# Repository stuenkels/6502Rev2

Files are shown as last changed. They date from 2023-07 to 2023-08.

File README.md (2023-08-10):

# 6502v2 Computer Build

Please note while this design is based on Ben Eaters 6502 (eater.net/6502) computer, it is not 100% compatible. This is mostly due to the memory map being changed to make space for 3 interface chips, 2 c22s and a c51. 

Memory Map:
  0x0000 -> 0x3FFF : RAM
  0x4010 : Start of memory for the "GPIO" VIA
  0x4020 : Start of memory for the "LCD" VIA
  0x4040 : Start of memory for the Serial interface
  0x8000 -> 0xFFFF : ROM

It is very simple to refactor any code written for the BE6502 to work with this design, all you have to do is change the definitions for the different ports, ex PORTB = $6020 would be PORTB = $4020.  

# Pictures
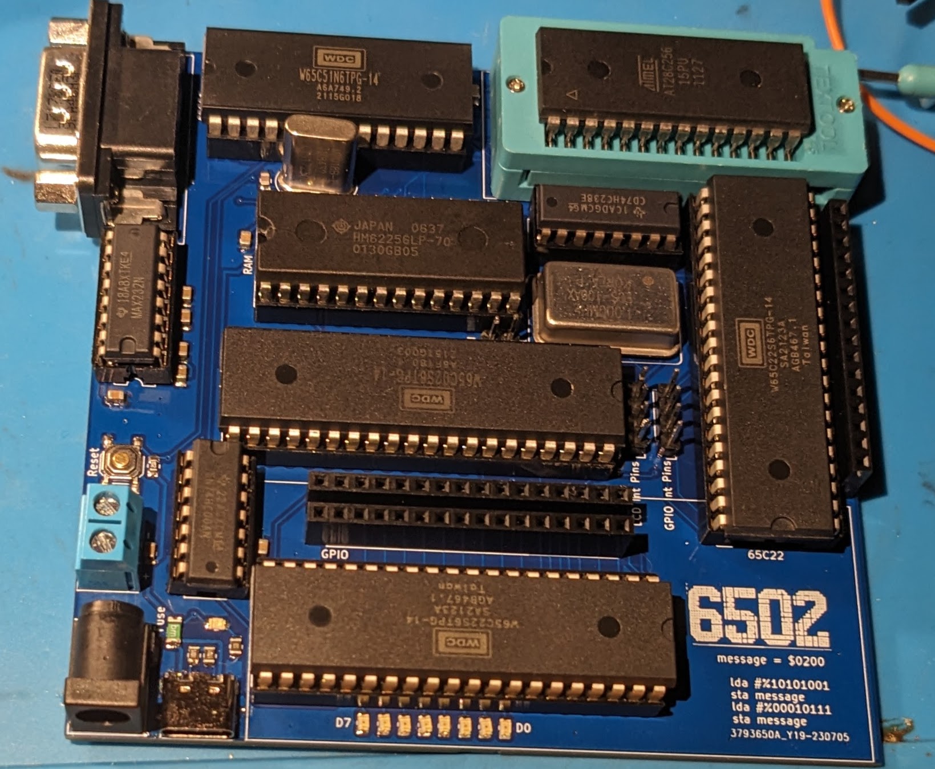
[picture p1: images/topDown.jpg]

<br>
The LCD header was mirrored on this first run of boards, the GERBER files and KiCad project have been updated in the repo.

If you want to build this PCB yourself, you can download the gerber.zip file and order it from JLCPCB or PCBWAY
MAKE SURE TO USE A FEMALE DB9 CONNECTOR FOR THE SERIAL PORT!!! The connecture in the picture is a male connector, and it does not work because the pins are in the wrong spots!

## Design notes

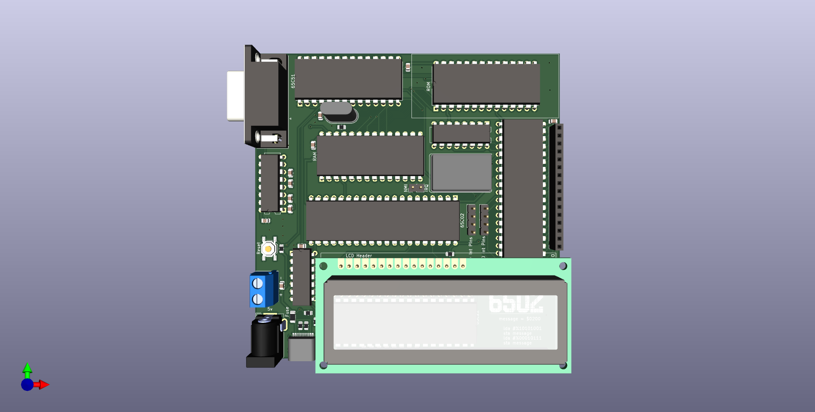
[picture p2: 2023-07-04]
images/pcb-3dRender.png

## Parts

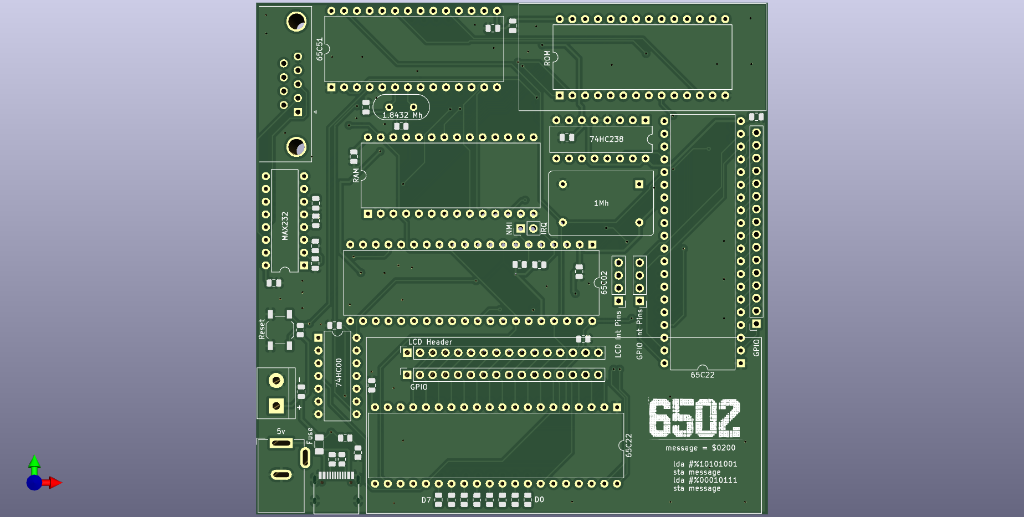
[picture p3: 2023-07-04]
images/pcb-3dWithoutComponents.png

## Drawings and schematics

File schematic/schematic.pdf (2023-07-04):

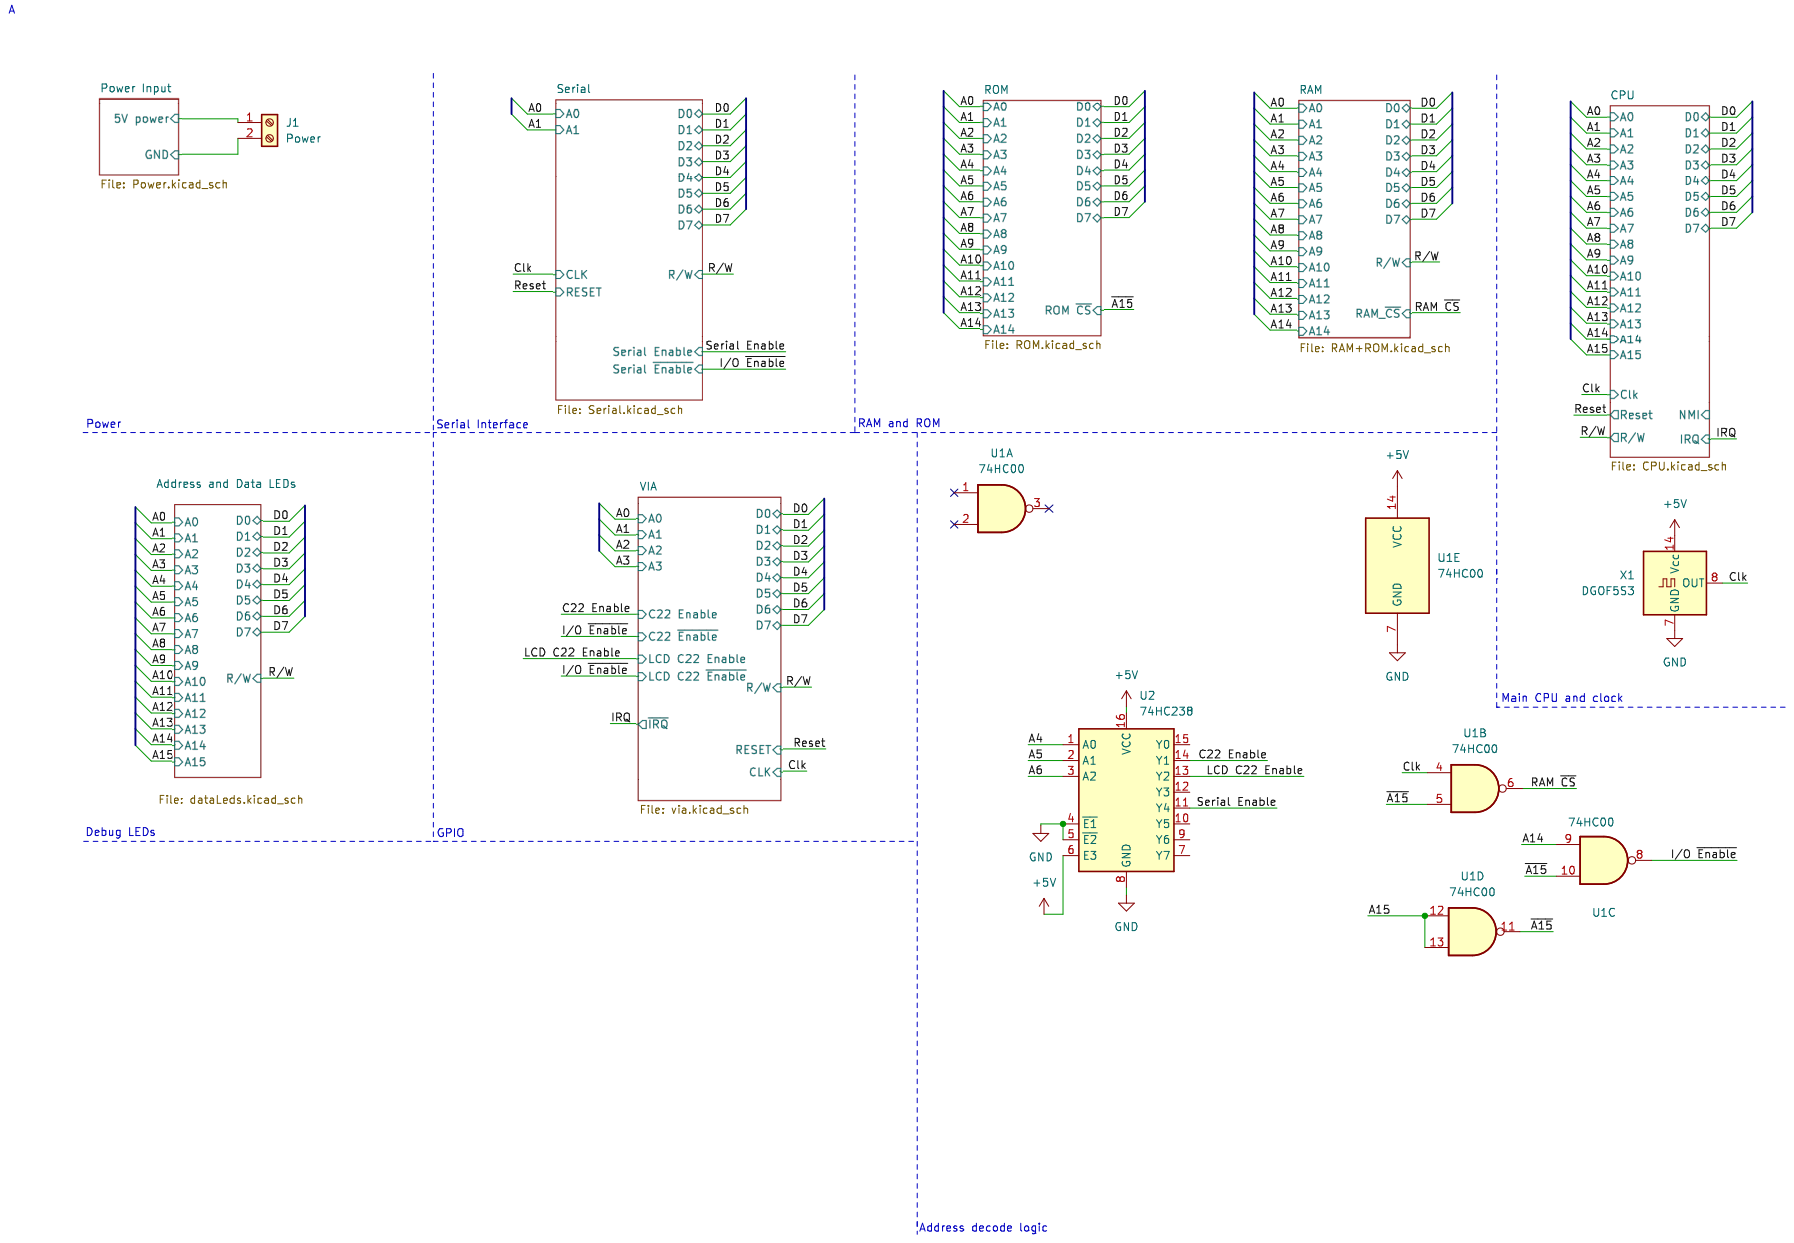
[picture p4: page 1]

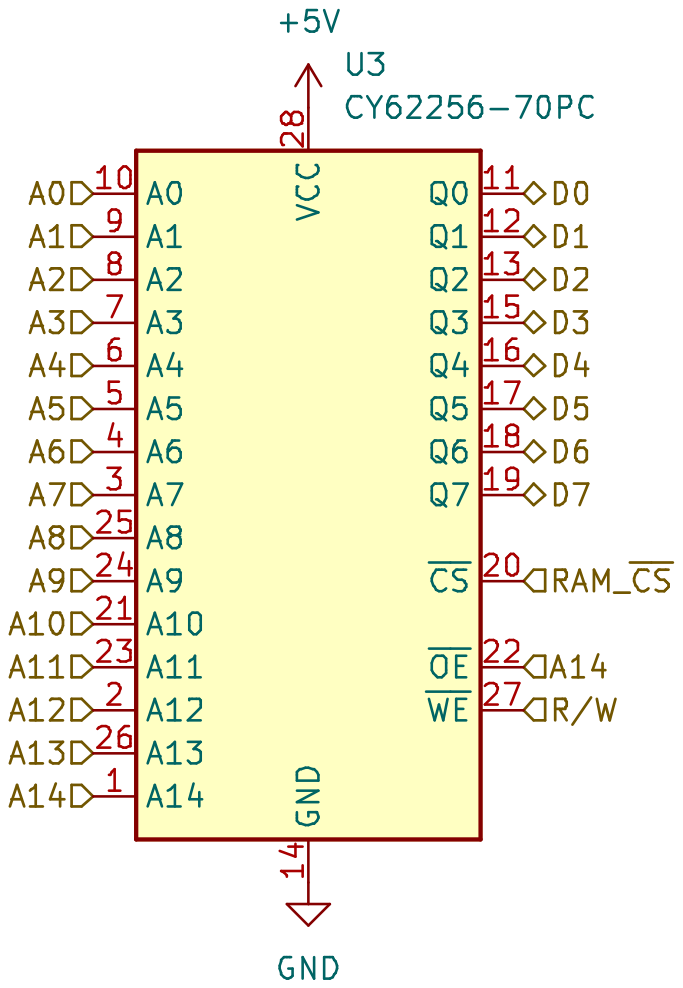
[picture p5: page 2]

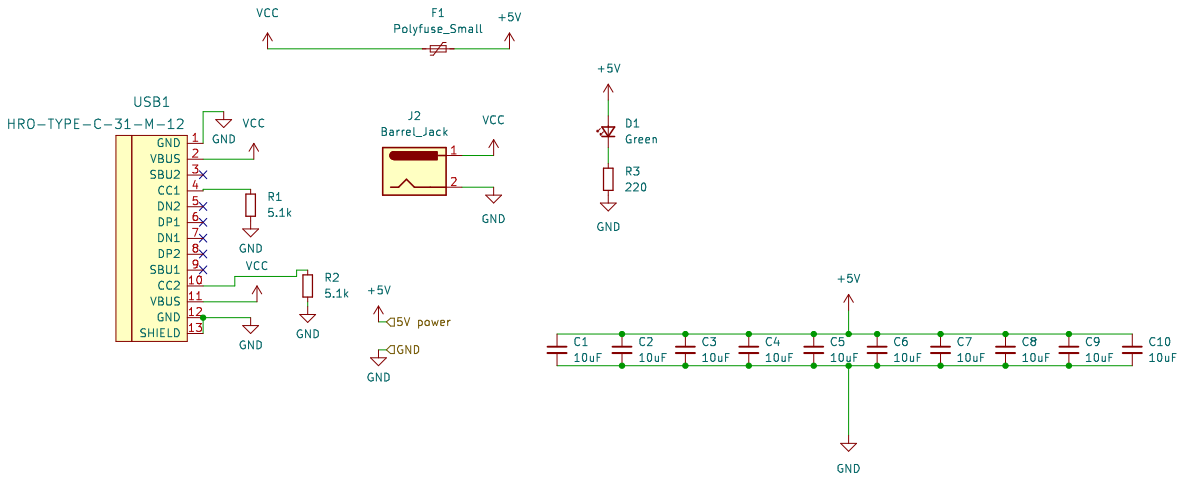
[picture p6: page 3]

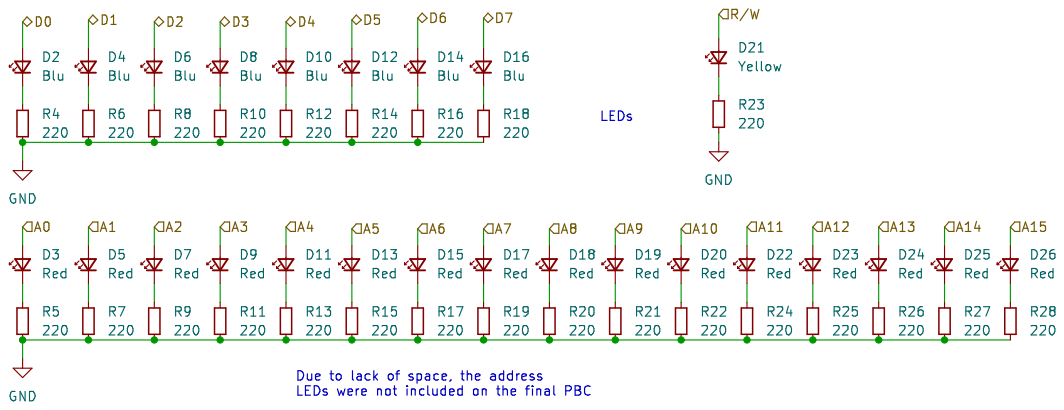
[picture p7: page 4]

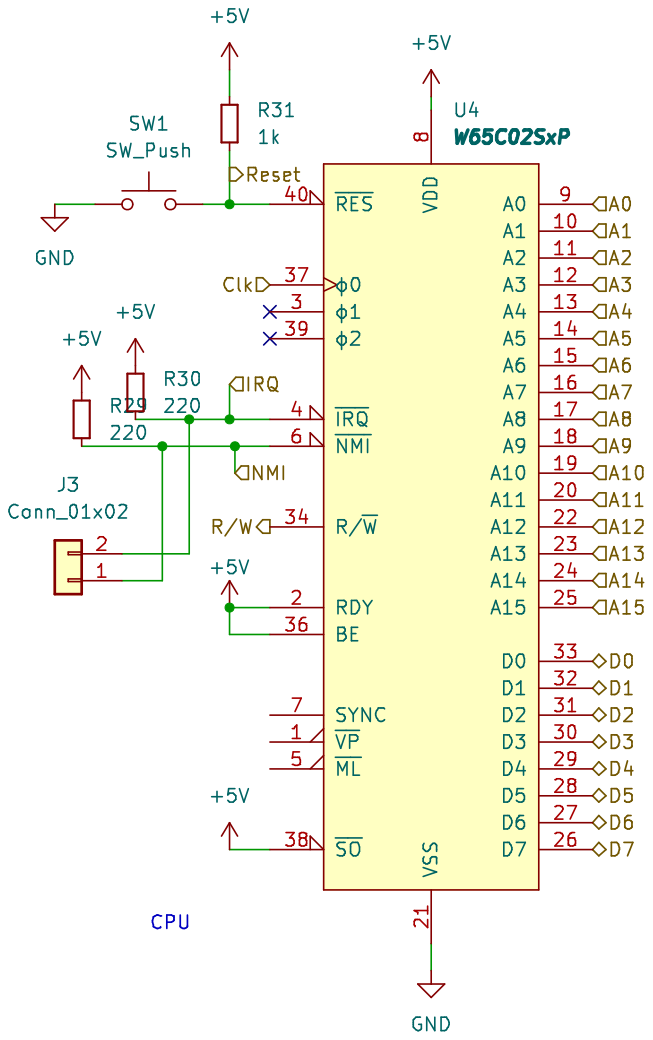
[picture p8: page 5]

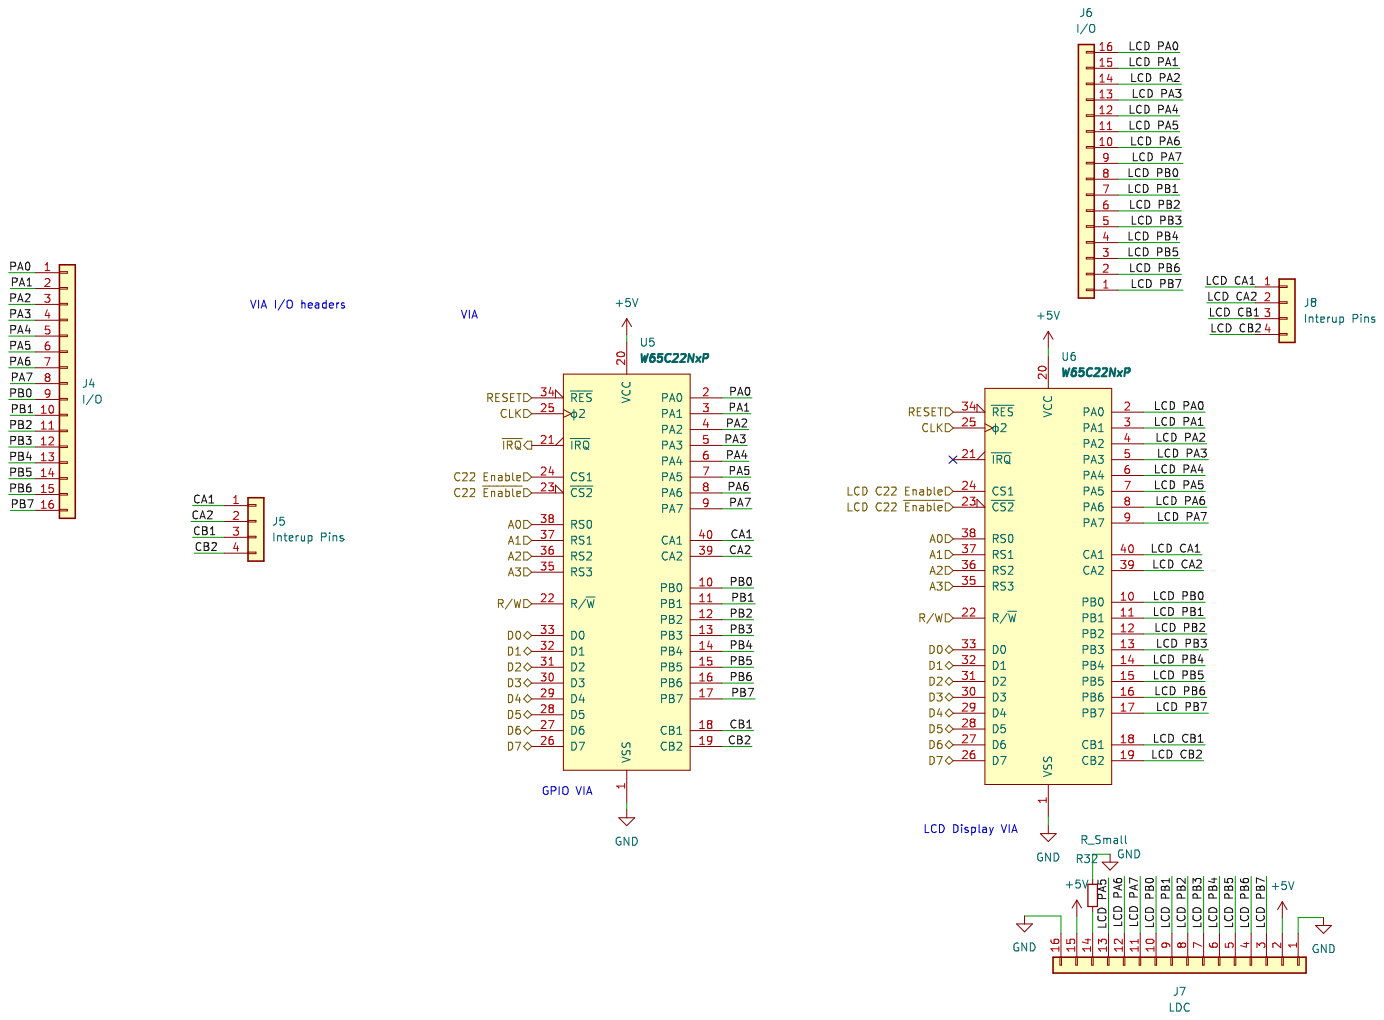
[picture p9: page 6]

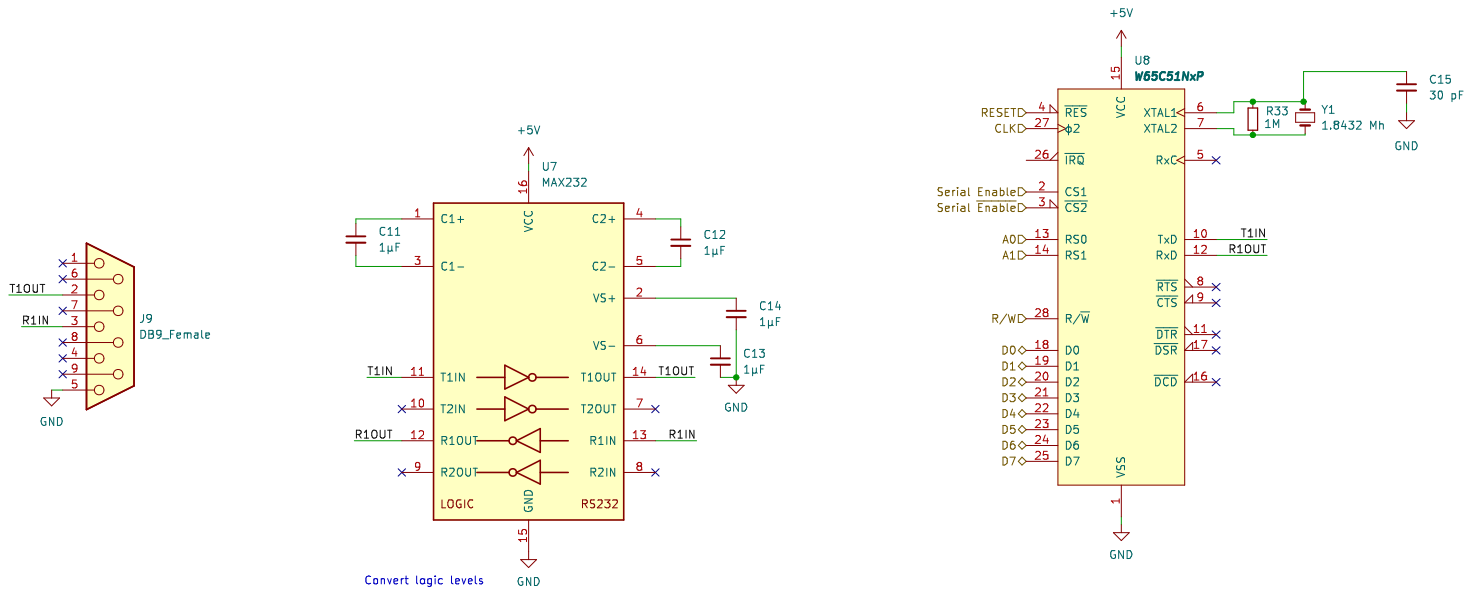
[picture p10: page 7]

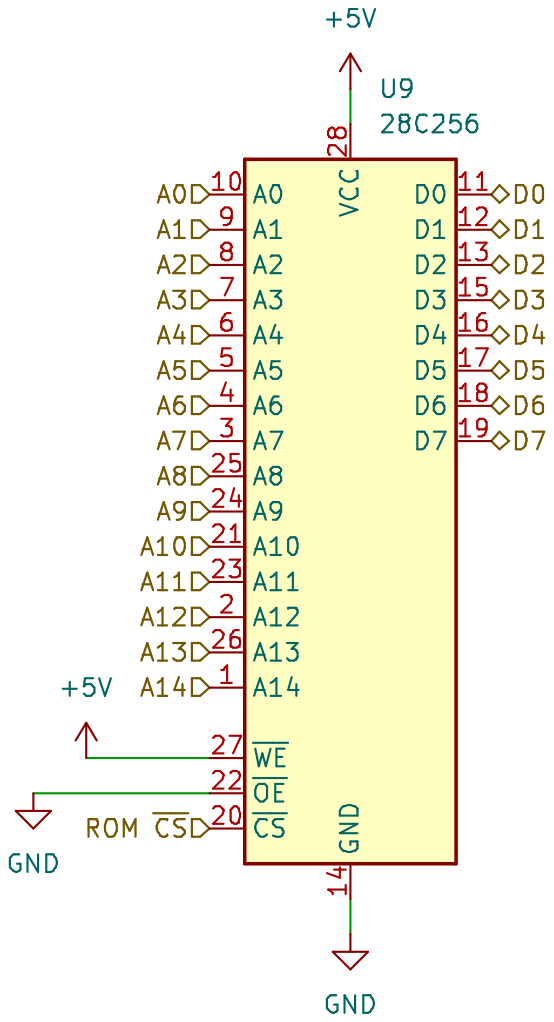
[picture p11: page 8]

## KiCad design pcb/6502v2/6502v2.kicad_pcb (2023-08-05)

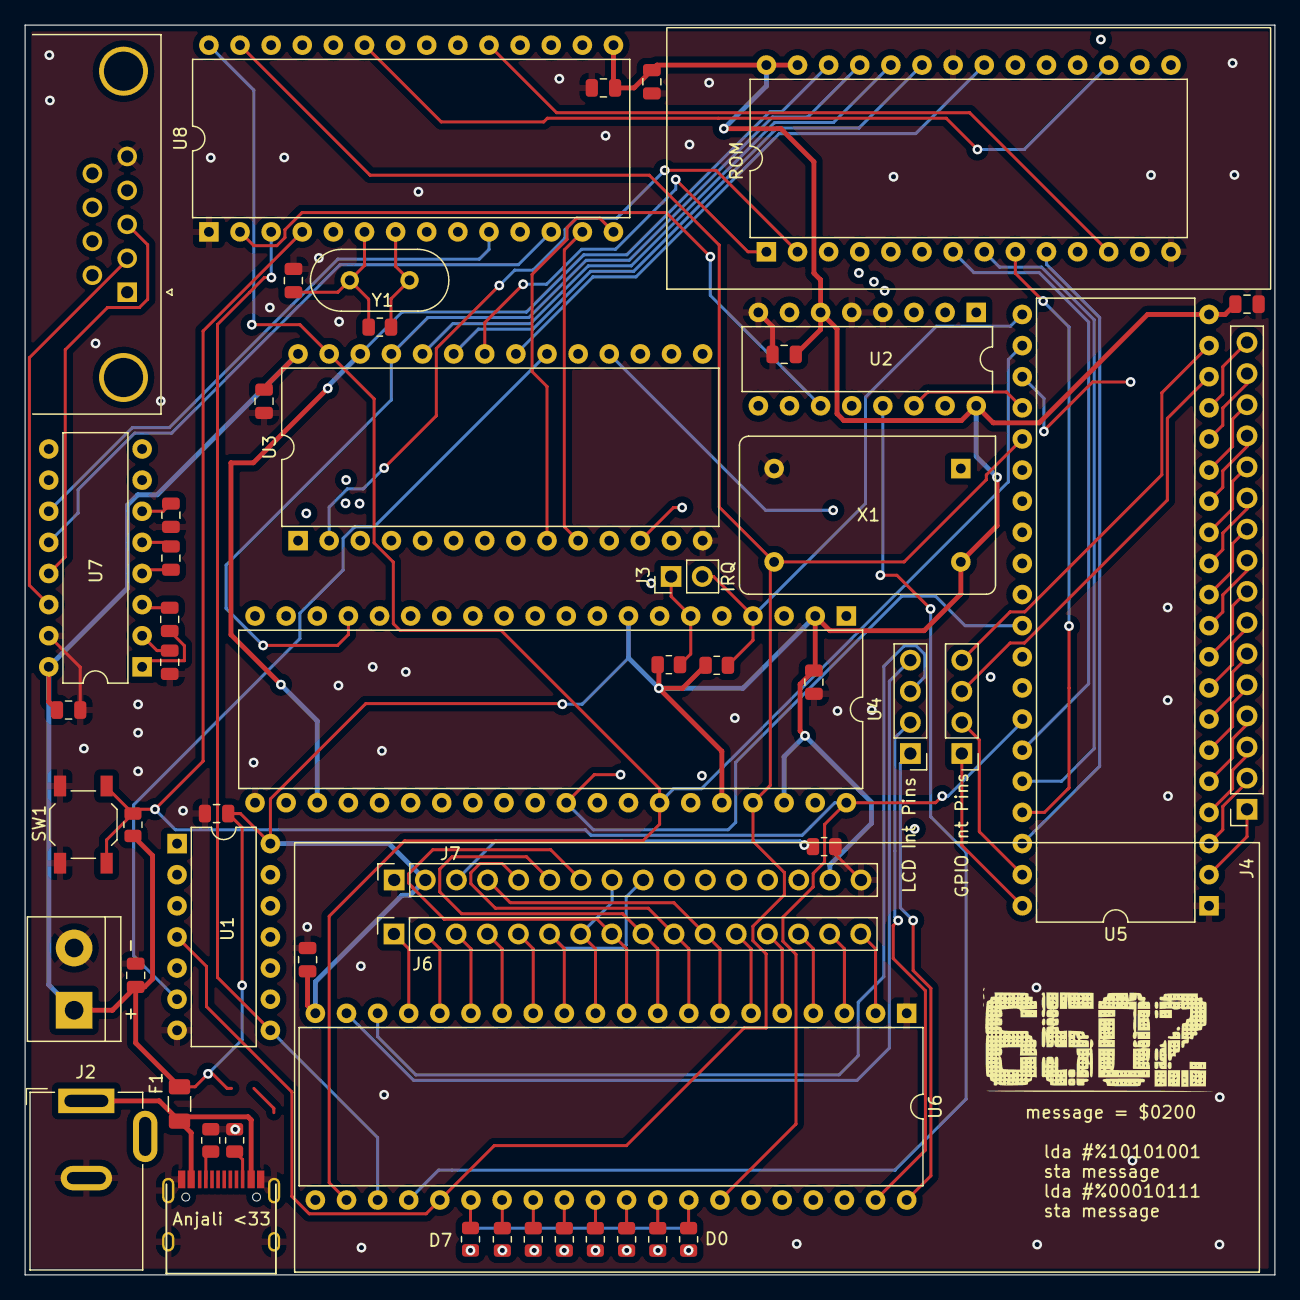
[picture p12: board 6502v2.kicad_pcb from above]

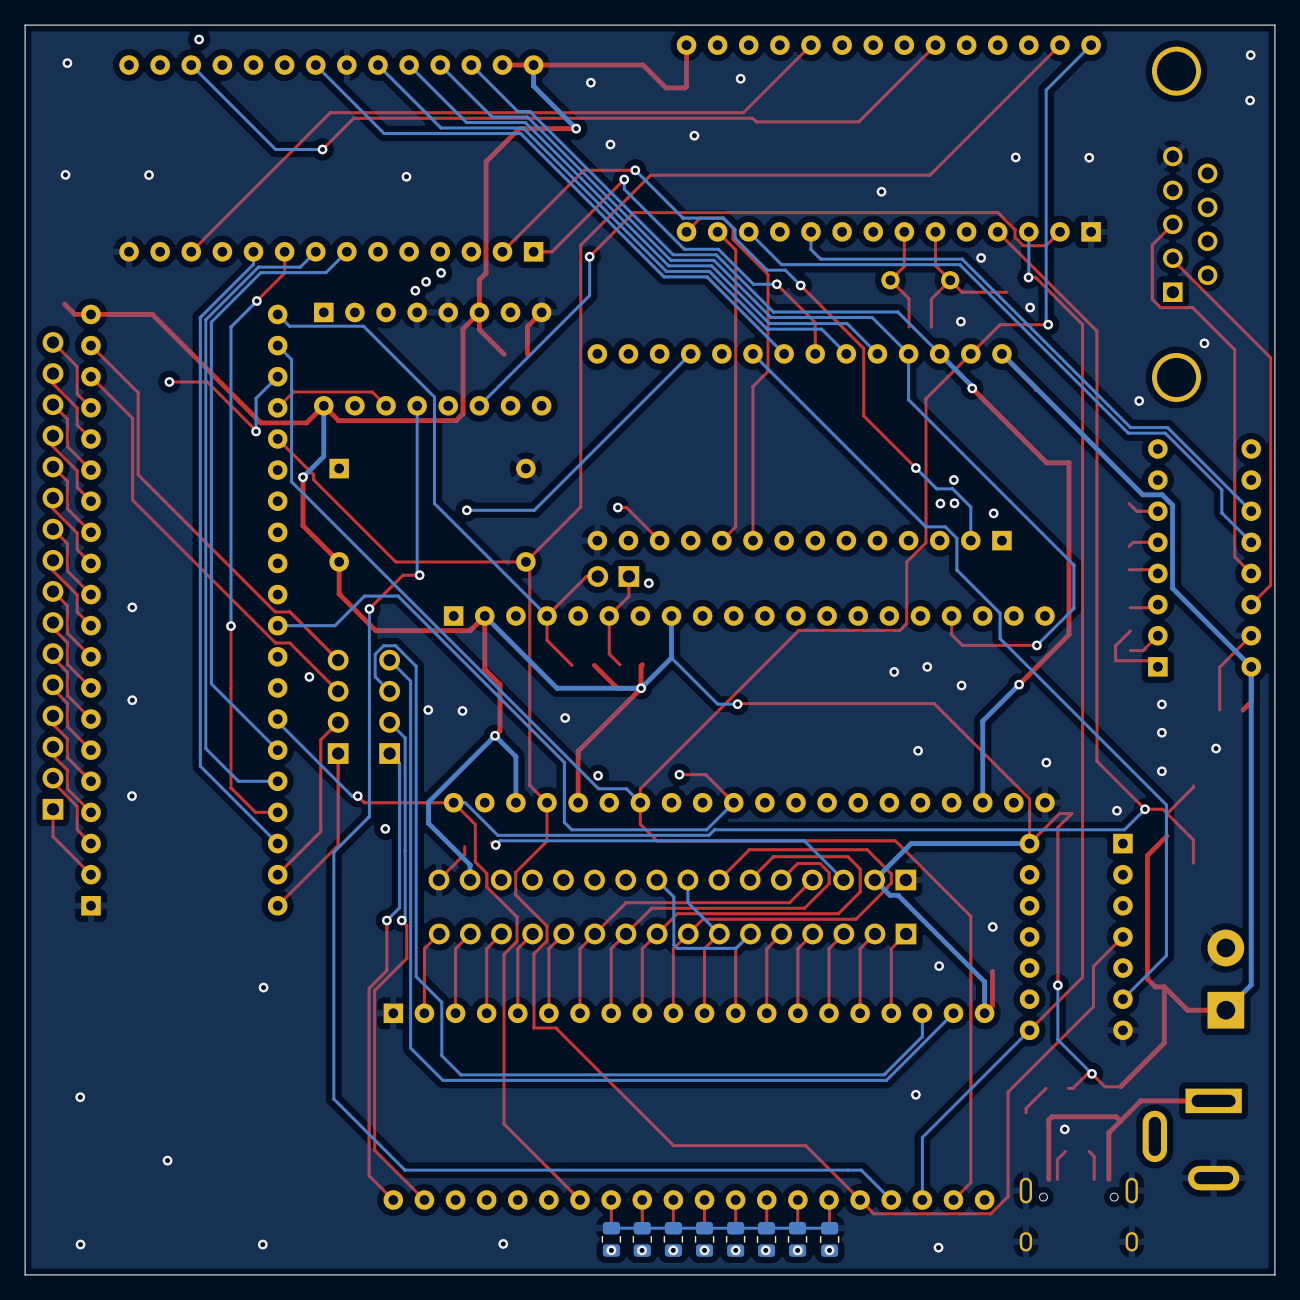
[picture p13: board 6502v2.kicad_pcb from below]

Board: 4 copper layers, 102.0 x 102.0 mm, 61 parts (8 on the bottom side), 101 nets.

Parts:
C1, C2, C3, C4, C5, C6, C7, C8, C9, C10: 10uF; C_0805_2012Metric
C11, C12, C13, C14: 1µF; C_0805_2012Metric
C15: 30 pF; C_0805_2012Metric
D2, D4, D6, D8, D10, D12, D14, D16: Blu; R_0805_2012Metric
F1: Polyfuse_Small; Fuse_1206_3216Metric
J1: Power; TerminalBlock_bornier-2_P5.08mm
J2: Barrel_Jack; BarrelJack_GCT_DCJ200-10-A_Horizontal
J3: Conn_01x02; PinHeader_1x02_P2.54mm_Vertical
J4, J6: I/O; PinSocket_1x16_P2.54mm_Vertical
J5, J8: Interup Pins; PinHeader_1x04_P2.54mm_Vertical
J7: LDC; PinSocket_1x16_P2.54mm_Vertical
J9: DB9_Female; DSUB-9_Female_Horizontal_P2.77x2.84mm_EdgePinOffset4.94mm_H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
R1, R2: 5.1k; R_0805_2012Metric
R4, R6, R8, R10, R12, R14, R16, R18, R29, R30: 220; R_0805_2012Metric
R31: 1k; R_0805_2012Metric
R32: R_Small; R_0805_2012Metric
R33: 1M; R_0805_2012Metric
SW1: SW_Push; SW_SPST_TL3342
U1: 74HC00; DIP-14_W7.62mm
U2: 74HC238; DIP-16_W7.62mm
U3: CY62256-70PC; DIP-28_W15.24mm
U4: W65C02SxP; DIP-40_W15.24mm
U5, U6: W65C22NxP; DIP-40_W15.24mm
U7: MAX232; DIP-16_W7.62mm
U8: W65C51NxP; DIP-28_W15.24mm
U9: 28C256; DIP-28_W15.24mm
USB1: HRO-TYPE-C-31-M-12
X1: DGOF5S3; Oscillator_DIP-14
Y1: 1.8432 Mh; Crystal_HC49-U_Vertical

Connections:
+5V: C1.1, C2.1, C3.1, C4.1, C5.1, C6.1, C7.1, C8.1, C9.1, C10.1, F1.2, J1.1, J7.2, J7.15, R29.1, R30.1, R31.1, U1.14 (VCC), U2.6 (E3), U2.16 (VCC), U3.28 (VCC), U4.2 (RDY), U4.8 (VDD), U4.36 (BE), U4.38 (~SO), U5.20 (VCC), U6.20 (VCC), U7.16 (VCC), U8.15 (VCC), U9.27 (~WE), U9.28 (VCC), X1.14 (Vcc)
/A0: U3.10 (A0), U4.9 (A0), U5.38 (RS0), U6.38 (RS0), U8.13 (RS0), U9.10 (A0)
/A1: U3.9 (A1), U4.10 (A1), U5.37 (RS1), U6.37 (RS1), U8.14 (RS1), U9.9 (A1)
/A2: U3.8 (A2), U4.11 (A2), U5.36 (RS2), U6.36 (RS2), U9.8 (A2)
/A3: U3.7 (A3), U4.12 (A3), U5.35 (RS3), U6.35 (RS3), U9.7 (A3)
/A4: U2.1 (A0), U3.6 (A4), U4.13 (A4), U9.6 (A4)
/A5: U2.2 (A1), U3.5 (A5), U4.14 (A5), U9.5 (A5)
/A6: U2.3 (A2), U3.4 (A6), U4.15 (A6), U9.4 (A6)
/A7: U3.3 (A7), U4.16 (A7), U9.3 (A7)
/A8: U3.25 (A8), U4.17 (A8), U9.25 (A8)
/A9: U3.24 (A9), U4.18 (A9), U9.24 (A9)
/A10: U3.21 (A10), U4.19 (A10), U9.21 (A10)
/A11: U3.23 (A11), U4.20 (A11), U9.23 (A11)
/A12: U3.2 (A12), U4.22 (A12), U9.2 (A12)
/A13: U3.26 (A13), U4.23 (A13), U9.26 (A13)
/A14: U1.9, U3.1 (A14), U3.22 (~OE), U4.24 (A14), U9.1 (A14)
/A15: U1.12, U1.13, U4.25 (A15)
/C22 Enable: U2.14 (Y1), U5.24 (CS1)
/CPU/NMI: J3.1, R29.2, U4.6 (~NMI)
/Clk: U1.4, U4.37 (ϕ0), U5.25 (ϕ2), U6.25 (ϕ2), U8.27 (ϕ2), X1.8 (OUT)
/D0: D2.2 (A), U3.11 (Q0), U4.33 (D0), U5.33 (D0), U6.33 (D0), U8.18 (D0), U9.11 (D0)
/D1: D4.2 (A), U3.12 (Q1), U4.32 (D1), U5.32 (D1), U6.32 (D1), U8.19 (D1), U9.12 (D1)
/D2: D6.2 (A), U3.13 (Q2), U4.31 (D2), U5.31 (D2), U6.31 (D2), U8.20 (D2), U9.13 (D2)
/D3: D8.2 (A), U3.15 (Q3), U4.30 (D3), U5.30 (D3), U6.30 (D3), U8.21 (D3), U9.15 (D3)
/D4: D10.2 (A), U3.16 (Q4), U4.29 (D4), U5.29 (D4), U6.29 (D4), U8.22 (D4), U9.16 (D4)
/D5: D12.2 (A), U3.17 (Q5), U4.28 (D5), U5.28 (D5), U6.28 (D5), U8.23 (D5), U9.17 (D5)
/D6: D14.2 (A), U3.18 (Q6), U4.27 (D6), U5.27 (D6), U6.27 (D6), U8.24 (D6), U9.18 (D6)
/D7: D16.2 (A), U3.19 (Q7), U4.26 (D7), U5.26 (D7), U6.26 (D7), U8.25 (D7), U9.19 (D7)
/IRQ: J3.2, R30.2, U4.4 (~IRQ), U5.21 (~IRQ)
/I/O ~Enable: U1.8, U5.23 (~CS2), U6.23 (~CS2), U8.3 (~CS2)
/LCD C22 Enable: U2.13 (Y2), U6.24 (CS1)
/RAM ~CS: U1.6, U3.20 (~CS)
/Reset: R31.2, SW1.2, U4.40 (~RES), U5.34 (~RES), U6.34 (~RES), U8.4 (~RES)
/R/W: U3.27 (~WE), U4.34 (R/~W), U5.22 (R/~W), U6.22 (R/~W), U8.28 (R/~W)
/Serial Enable: U2.11 (Y4), U8.2 (CS1)
/Serial/R1IN: J9.3, U7.13 (R1IN)
/Serial/R1OUT: U7.12 (R1OUT), U8.12 (RxD)
/Serial/T1IN: U7.11 (T1IN), U8.10 (TxD)
/Serial/T1OUT: J9.2, U7.14 (T1OUT)
/VIA/CA1: J5.1, U5.40 (CA1)
/VIA/CA2: J5.2, U5.39 (CA2)
/VIA/CB1: J5.3, U5.18 (CB1)
/VIA/CB2: J5.4, U5.19 (CB2)
/VIA/LCD CA1: J8.1, U6.40 (CA1)
/VIA/LCD CA2: J8.2, U6.39 (CA2)
/VIA/LCD CB1: J8.3, U6.18 (CB1)
/VIA/LCD CB2: J8.4, U6.19 (CB2)
/VIA/LCD PA0: J6.16, U6.2 (PA0)
/VIA/LCD PA1: J6.15, U6.3 (PA1)
/VIA/LCD PA2: J6.14, U6.4 (PA2)
/VIA/LCD PA3: J6.13, U6.5 (PA3)
/VIA/LCD PA4: J6.12, U6.6 (PA4)
/VIA/LCD PA5: J6.11, J7.4, U6.7 (PA5)
/VIA/LCD PA6: J6.10, J7.5, U6.8 (PA6)
/VIA/LCD PA7: J6.9, J7.6, U6.9 (PA7)
/VIA/LCD PB0: J6.8, J7.7, U6.10 (PB0)
/VIA/LCD PB1: J6.7, J7.8, U6.11 (PB1)
/VIA/LCD PB2: J6.6, J7.9, U6.12 (PB2)
/VIA/LCD PB3: J6.5, J7.10, U6.13 (PB3)
/VIA/LCD PB4: J6.4, J7.11, U6.14 (PB4)
/VIA/LCD PB5: J6.3, J7.12, U6.15 (PB5)
/VIA/LCD PB6: J6.2, J7.13, U6.16 (PB6)
/VIA/LCD PB7: J6.1, J7.14, U6.17 (PB7)
/VIA/PA0: J4.1, U5.2 (PA0)
/VIA/PA1: J4.2, U5.3 (PA1)
/VIA/PA2: J4.3, U5.4 (PA2)
/VIA/PA3: J4.4, U5.5 (PA3)
/VIA/PA4: J4.5, U5.6 (PA4)
/VIA/PA5: J4.6, U5.7 (PA5)
/VIA/PA6: J4.7, U5.8 (PA6)
/VIA/PA7: J4.8, U5.9 (PA7)
/VIA/PB0: J4.9, U5.10 (PB0)
/VIA/PB1: J4.10, U5.11 (PB1)
/VIA/PB2: J4.11, U5.12 (PB2)
/VIA/PB3: J4.12, U5.13 (PB3)
/VIA/PB4: J4.13, U5.14 (PB4)
/VIA/PB5: J4.14, U5.15 (PB5)
/VIA/PB6: J4.15, U5.16 (PB6)
/VIA/PB7: J4.16, U5.17 (PB7)
/~A15: U1.5, U1.10, U1.11, U9.20 (~CS)
GND: C1.2, C2.2, C3.2, C4.2, C5.2, C6.2, C7.2, C8.2, C9.2, C10.2, C13.2, C14.2, C15.2, J1.2, J2.2, J7.1, J7.16, J9.5, R1.2, R2.2, R4.2, R6.2, R8.2, R10.2, R12.2, R14.2, R16.2, R18.2, R32.2, SW1.1, U1.7 (GND), U2.4 (~E1), U2.5 (~E2), U2.8 (GND), U3.14 (GND), U4.21 (VSS), U5.1 (VSS), U6.1 (VSS), U7.15 (GND), U8.1 (VSS), U9.14 (GND), U9.22 (~OE), USB1.1 (GND), USB1.12 (GND), USB1.13 (SHIELD), X1.7 (GND)
unnamed: C11.1, U7.1 (C1+)
unnamed: C11.2, U7.3 (C1-)
unnamed: C12.1, U7.4 (C2+)
unnamed: C12.2, U7.5 (C2-)
unnamed: C13.1, U7.6 (VS-)
unnamed: C14.1, U7.2 (VS+)
unnamed: C15.1, R33.1, U8.6 (XTAL1), Y1.2
unnamed: D2.1 (K), R4.1
unnamed: D4.1 (K), R6.1
unnamed: D6.1 (K), R8.1
unnamed: D8.1 (K), R10.1
unnamed: D10.1 (K), R12.1
unnamed: D12.1 (K), R14.1
unnamed: D14.1 (K), R16.1
unnamed: D16.1 (K), R18.1
unnamed: J7.3, R32.1
unnamed: R1.1, USB1.4 (CC1)
unnamed: R2.1, USB1.10 (CC2)
unnamed: R33.2, U8.7 (XTAL2), Y1.1
VCC: F1.1, J2.1, USB1.2 (VBUS), USB1.11 (VBUS)

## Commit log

2023-06-23 Change filenames
    [6502v2.kicad_pcb, 6502v2.kicad_sch]
2023-06-23 fles change
    [6502v2.kicad_pcb, 6502v2.kicad_sch]
2023-06-23 Update schematic
    [6502v2.kicad_sch]
2023-06-30 Changed stufffs
    [6502v2.kicad_sch, CPU.kicad_sch, Power.kicad_sch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]
2023-06-30 UART more like u r dumb
    [6502v2.kicad_sch, CPU.kicad_sch, Serial.kicad_sch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]
2023-07-01 Finally figured out the address decode logic, hopefully im done for now
    [6502v2.kicad_sch, RAM+ROM.kicad_sch, ROM.kicad_sch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]
2023-07-02 just working
    [6502v2.kicad_pcb, 6502v2.kicad_sch, CPU.kicad_sch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]
2023-07-02 Laying out chips
    [6502v2.kicad_pcb, 6502v2.kicad_sch]
2023-07-03 Yo yo yo i make the bord 102 by 102 cause jlc pricing
    [6502v2.kicad_pcb, 6502v2.kicad_sch, CPU.kicad_sch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]
2023-07-04 First pass at routing done, now comes double checking everything
    [6502v2.kicad_pcb, 6502v2.kicad_sch, CPU.kicad_sch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]
2023-07-04 Tidying up schematic
    [6502v2.kicad_pcb, 6502v2.kicad_sch, dataLeds.kicad_sch]
2023-07-04 Oh\?\!\?\!\? Is that a gerber i see\?\!\?\!
    [6502v2-B_Cu.gbr, 6502v2-B_Mask.gbr, 6502v2-B_Paste.gbr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]
2023-07-04 Ok i rembered to generate drill files this time
    [6502v2-B_Cu.gbr, 6502v2-B_Mask.gbr, 6502v2-B_Paste.gbr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]
2023-07-04 Finishing up
    [6502v2-B_Cu.gbr, 6502v2-B_Mask.gbr, 6502v2-B_Paste.gbr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]
2023-07-05 Removed burried VIAs because jlc cant produce them
    [6502v2-B_Cu.gbr, 6502v2-B_Mask.gbr, 6502v2-B_Paste.gbr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]
2023-08-05 Fixed mirrored footprints, updated readme
    [6502v2-B_Cu.gbr, 6502v2-B_Mask.gbr, 6502v2-B_Paste.gbr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]
